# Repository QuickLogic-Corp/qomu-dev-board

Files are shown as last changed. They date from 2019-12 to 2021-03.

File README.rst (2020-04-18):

======================
Qomu Development Board
======================

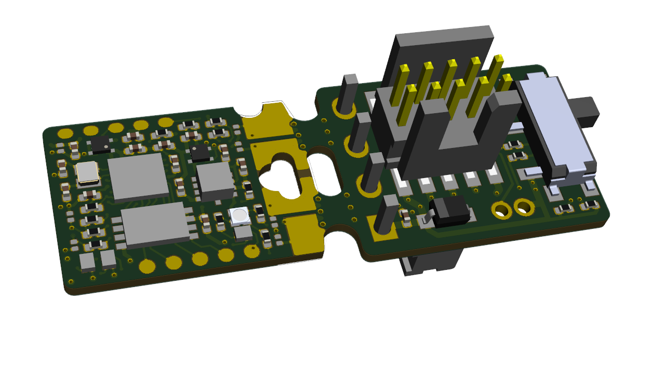
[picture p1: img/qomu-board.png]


Overview
========

This repository contains open hardware design files for a development board based on the Quicklogic `EOS S3 Sensor Processing Platform <https://www.quicklogic.com/products/eos-s3/>`_.
The design files were created by `Antmicro <https://www.antmicro.com>`_ in cooperation with `Quicklogic <https://www.quicklogic.com/>`_.
The board is small enough to fit into a USB socket.
This allows the user to explore functionalities of the EOS S3 platform on the go without cables or taking up space on your desk.
The board has an additional break-away part with debug connectors that speed up initial bringup and software development.

Key features
============

* EOS S3 Sensor Processing Platform
* 16Mbit of external flash memory
* Accelerometer
* User RGB LED
* Capacitive touch pads
* Supplied with 5.0VDC from USB port
* USB data signals tied to programmable logic

Layout and dimensions
=====================

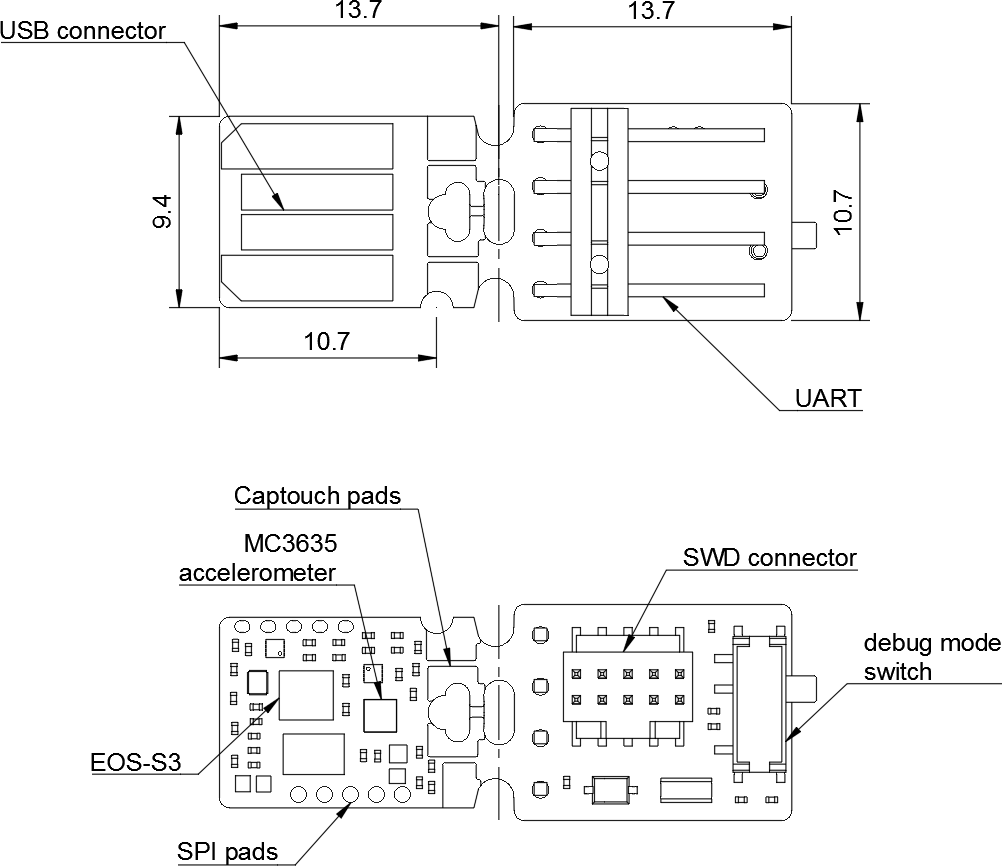
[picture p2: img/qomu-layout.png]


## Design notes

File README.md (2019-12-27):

# qomu-dev-board
Qomu Development Board for EOS S3

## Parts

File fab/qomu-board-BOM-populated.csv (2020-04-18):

Reference | Quantity | Value | Footprint | Manufacturer | MPN
C1 C2 C7 C9 | 4 | C_2u2_0201 | C_0201_0603Metric | Samsung | CL03A225MP3CRNC
C10 C11 C12 C3 C4 C5 C6 C8 | 8 | C_100n_0201 | C_0201_0603Metric | Murata | GRM033R60J104KE19D
C13 C14 | 2 | C_8p_0201 | C_0201_0603Metric | Murata | GRM0335C1E8R0DA01D
D1 D2 D3 D4 D5 D6 D7 | 7 | D_Small-Device | X1-DFN1006-2 | Diodes Inc. | D5V0L1B2LP3-7
D8 | 1 | SD05C.TCT | SOD-323-SD05 | Semtec | SD05C.TCT
IC1 | 1 | EOS-S3 | 42-WLCSP | Quicklogic | EOS-S3-42-WLCSP
J1 | 1 | FTSH-105-01-L-DV-K | PinHeader_2x5_P1.27_SMD | Samtec Inc. | FTSH-105-01-L-DV-K
J2 | 1 | 825437-4 | TE_825437-4 | TE Connectivity | 825437-4
J3 | 1 | MC-HVT1-S02-G | PinHeader_1x2_P1.27mm_Drill.7mm_with_622002115121_plug | Multicomp | MC-HVT1-S02-G
Q1 Q2 Q3 | 3 | RV1C002UN | VML0806 | ROHM Semiconductor | RV1C002UN
R1 R13 R15 R2 R3 R4 R5 R6 | 8 | R_10k_0201 | R_0201_0603Metric | Panasonic | ERJ1GNF1002C
R10 R7 | 2 | R_0R_0201 | R_0201_0603Metric | Multicomp | MCRE000086
R11 R12 | 2 | R_22R_0201 | R_0201_0603Metric | Multicomp | MCRE000100
R16 R17 | 2 | R_100R_0201 | R_0201_0603Metric | Multicomp | MCRE000116
R18 | 1 | R_220R_0201 | R_0201_0603Metric | Multicomp | MCRE000124
R8 | 1 | R_4k7_0201 | R_0201_0603Metric | Vishay | CRCW02014K70FNED
R9 | 1 | R_1k5_0201 | R_0201_0603Metric | Multicomp | MCRE000144
S1 | 1 | MSS3-V-T_R | Switch_Slide_MSS3 | Diptronics | MSS3-V-T/R
U1 U2 | 2 | LDO-X2SON | Texas_X2SON-4_1x1mm_P0.65mm | Microchip | MIC5504-3.3YMT
U10 | 1 | RGB-LED | LED-RGB-5DS-UHD1110-FKA | Cree | UHD1110-FKA
U4 | 1 | GD25Q16CEIGR | GD25Q16CEIGR | GigaDevice Semiconductor | GD25Q16CEIGR
U5 | 1 | MC3635 | MC3635 | mCube | MC3635
XTAL1 | 1 | ECS-_327-12_5-1210-TR | XTAL_ECS-.327-12.5-1210-TR | ECS Inc. | ECS-.327-12.5-1210-TR

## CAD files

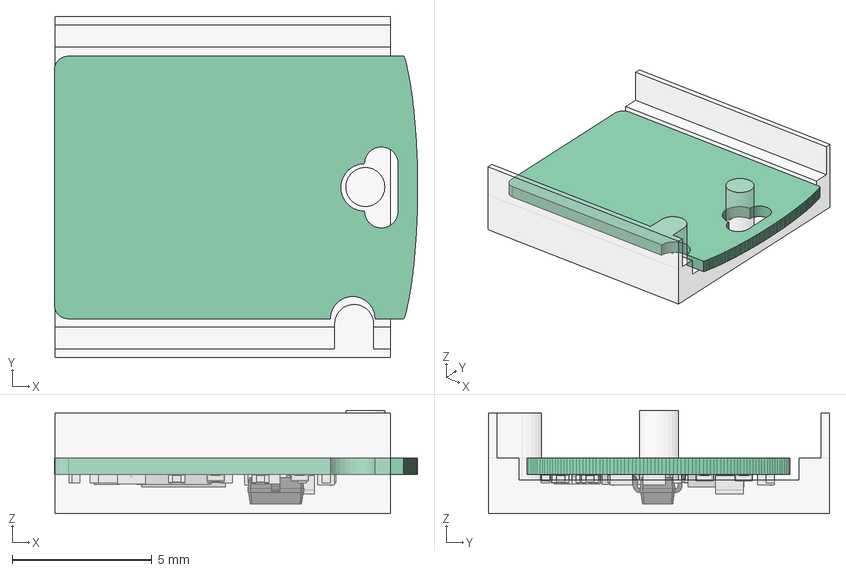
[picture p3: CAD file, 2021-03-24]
case/case-bare-0.0.FCStd
13.0 x 12.2 x 3.70 mm
Pcb
U2_X2SON-DQN0004A_5DC58CFF
U1_X2SON-DQN0004A_5F5B4CDF
U10_LED-UHD1110-FKA_5DC5D065
U4_(Unsaved)_5DEEC34D
Q3_TRANS_RV1C001Z_ROM_5DF3B6C3
Q1_TRANS_RV1C001Z_ROM_5F9A5F46
Q2_TRANS_RV1C001Z_ROM_5DF9400C
C4_C_0201_0603Metric_5FB65D3D
U3_SOT_323_SC_70_5FC7136C
C15_C_0201_0603Metric_5FB66156
XTAL1_ECS-.327-12.5-1210-TR_5DF79E47
IC1_(Unsaved)_5F5BD09C
C7_C_0201_0603Metric_5DDDC17D
R1_R_0201_5DC5A0F0
C14_C_0201_0603Metric_5F9A3241
C13_C_0201_0603Metric_5DF97F66
R18_R_0201_5DEE54FD
R17_R_0201_5DF3BC3D
R16_R_0201_5DF3BCFD
R12_R_0201_5DF3BC6D
R11_R_0201_5DF3BC9D
R9_R_0201_5DF3BCCD
R5_R_0201_5F5B4C73
R2_R_0201_5DDDC491
D7_L_0201_0603Metric_5DC58C89
D6_L_0201_0603Metric_5DF818F3
D5_L_0201_0603Metric_5F5BD1CB
D4_L_0201_0603Metric_5DEE9B1D
D3_L_0201_0603Metric_5DC59080
D2_L_0201_0603Metric_5DC59071
D1_L_0201_0603Metric_5F5BBC78
C11_C_0201_0603Metric_5F5B4CA3
C10_C_0201_0603Metric_5DEFCC06
C9_C_0201_0603Metric_5DD5522E
C8_C_0201_0603Metric_5DEFCCB7
C6_C_0201_0603Metric_5DEFCBD0
C5_C_0201_0603Metric_5DF7B985
C3_C_0201_0603Metric_5DEFCE4F
C2_C_0201_0603Metric_5F5B4C43
C1_C_0201_0603Metric_5DDDBFF4
Case

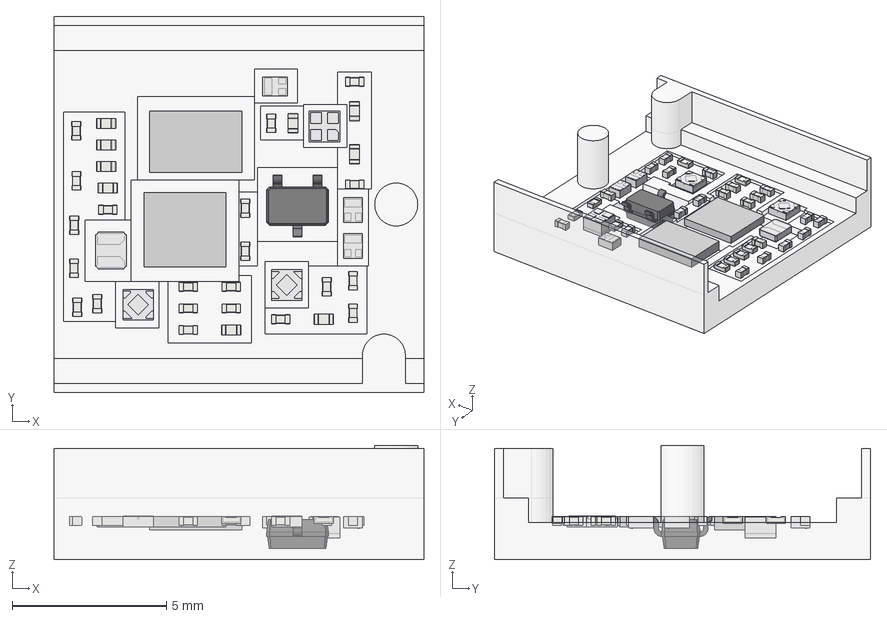
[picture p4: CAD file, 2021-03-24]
case/case-0.1.FCStd
12.0 x 12.2 x 3.70 mm
U2_X2SON-DQN0004A_5DC58CFF
U1_X2SON-DQN0004A_5F5B4CDF
U10_LED-UHD1110-FKA_5DC5D065
U4_(Unsaved)_5DEEC34D
Q3_TRANS_RV1C001Z_ROM_5DF3B6C3
Q1_TRANS_RV1C001Z_ROM_5F9A5F46
Q2_TRANS_RV1C001Z_ROM_5DF9400C
C4_C_0201_0603Metric_5FB65D3D
U3_SOT_323_SC_70_5FC7136C
C15_C_0201_0603Metric_5FB66156
XTAL1_ECS-.327-12.5-1210-TR_5DF79E47
IC1_(Unsaved)_5F5BD09C
C7_C_0201_0603Metric_5DDDC17D
R1_R_0201_5DC5A0F0
C14_C_0201_0603Metric_5F9A3241
C13_C_0201_0603Metric_5DF97F66
R18_R_0201_5DEE54FD
R17_R_0201_5DF3BC3D
R16_R_0201_5DF3BCFD
R12_R_0201_5DF3BC6D
R11_R_0201_5DF3BC9D
R9_R_0201_5DF3BCCD
R5_R_0201_5F5B4C73
R2_R_0201_5DDDC491
D7_L_0201_0603Metric_5DC58C89
D6_L_0201_0603Metric_5DF818F3
D5_L_0201_0603Metric_5F5BD1CB
D4_L_0201_0603Metric_5DEE9B1D
D3_L_0201_0603Metric_5DC59080
D2_L_0201_0603Metric_5DC59071
D1_L_0201_0603Metric_5F5BBC78
C11_C_0201_0603Metric_5F5B4CA3
C10_C_0201_0603Metric_5DEFCC06
C9_C_0201_0603Metric_5DD5522E
C8_C_0201_0603Metric_5DEFCCB7
C6_C_0201_0603Metric_5DEFCBD0
C5_C_0201_0603Metric_5DF7B985
C3_C_0201_0603Metric_5DEFCE4F
C2_C_0201_0603Metric_5F5B4C43
C1_C_0201_0603Metric_5DDDBFF4
Case

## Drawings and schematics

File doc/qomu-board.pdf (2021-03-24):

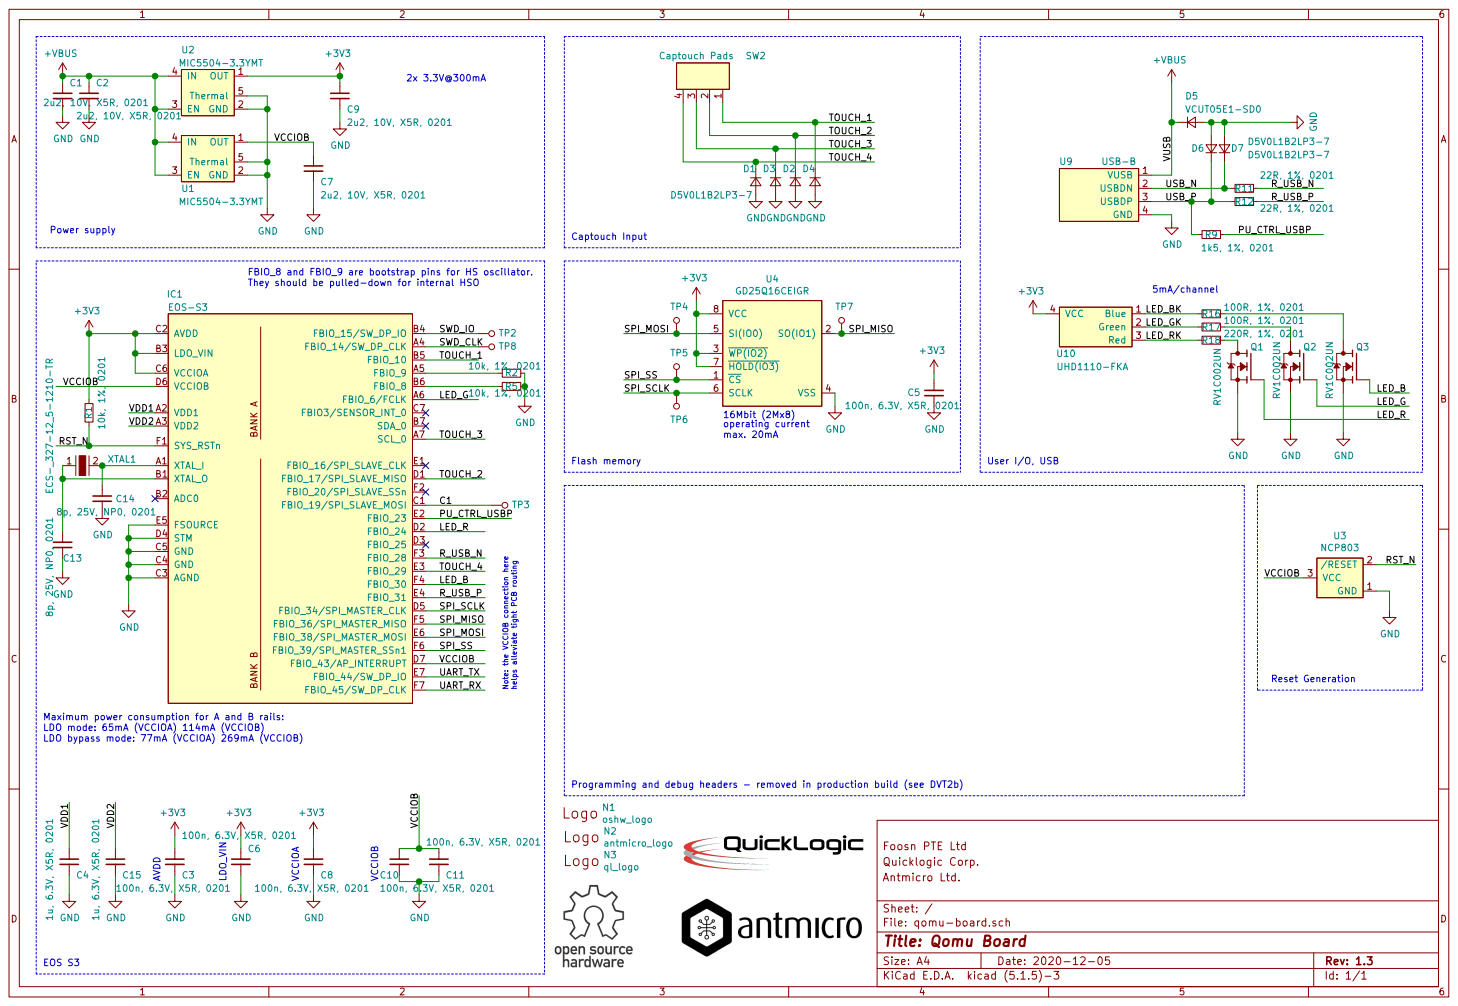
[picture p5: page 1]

They should be pulled-down for internal HSO VCCIOB

5mA/channel Note: the VCCIOB connection here helps alleviate tight PCB routing 2x 3.3V@300mA

FBIO_8 and FBIO_9 are bootstrap pins for HS oscillator.

SPI_MOSI Maximum power consumption for A and B rails:

File: qomu-board.sch Sheet: / Antmicro Ltd. Quicklogic Corp. Foosn PTE Ltd GND

LDO mode: 65mA (VCCIOA) 114mA (VCCIOB)
LDO bypass mode: 77mA (VCCIOA) 269mA (VCCIOB) LDO_VIN

Id: 1/1 Title: Qomu Board

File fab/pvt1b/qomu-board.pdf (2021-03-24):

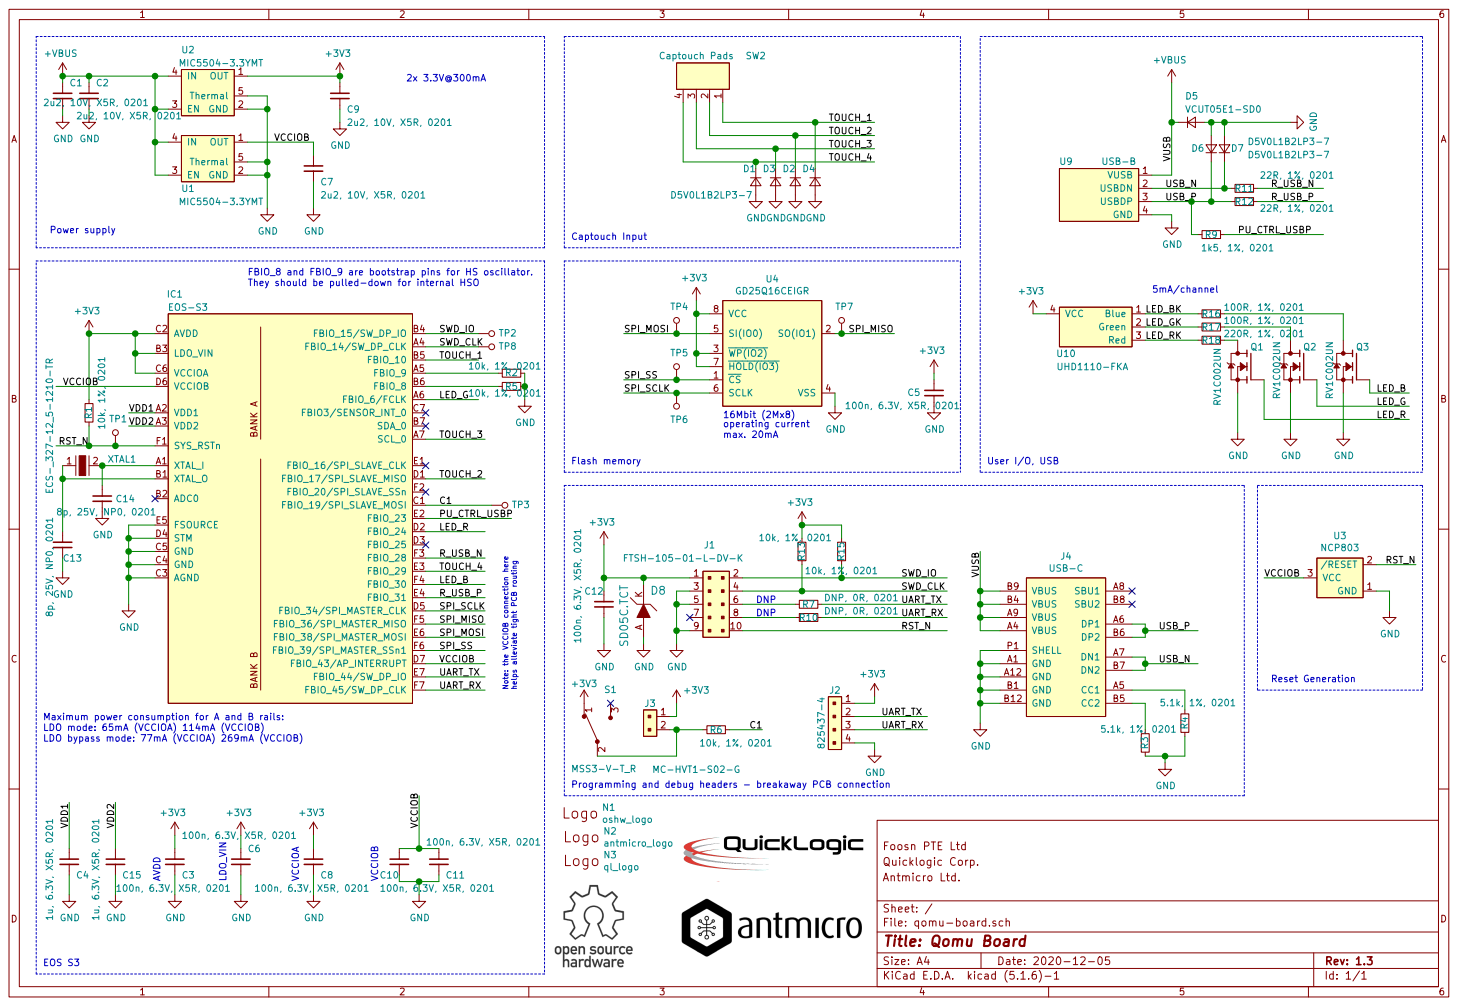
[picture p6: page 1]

1 Captouch Pads SW2 TP2 TP8 C4 1u, 6.3V, X5R, 0201 GND GND

They should be pulled-down for internal HSO LDO_VIN
IC1EOS-S3 GND GND

FBIO_8 and FBIO_9 are bootstrap pins for HS oscillator.

operating current max. 20mA AVDD

Programming and debug headers - breakaway PCB connection Note: the VCCIOB connection here helps alleviate tight PCB routing VCCIOB

SWD_CLK Maximum power consumption for A and B rails:

LDO mode: 65mA (VCCIOA) 114mA (VCCIOB)
LDO bypass mode: 77mA (VCCIOA) 269mA (VCCIOB)

File: qomu-board.sch Sheet: / Antmicro Ltd. Quicklogic Corp. Foosn PTE Ltd Logo N2

Id: 1/1 Title: Qomu Board

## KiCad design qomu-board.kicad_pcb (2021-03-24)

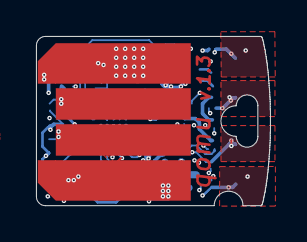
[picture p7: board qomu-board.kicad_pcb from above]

Board: 4 copper layers, 13.0 x 9.4 mm, 52 parts (0 on the bottom side), 36 nets.

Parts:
C1, C2, C7, C9: 2u2, 10V, X5R, 0201; C_0201_0603Metric
C3, C5, C6, C8, C10, C11: 100n, 6.3V, X5R, 0201; C_0201_0603Metric
C4: 1u, 6.3V, X5R, 0201; C_0201
C13, C14: 8p, 25V, NP0, 0201; C_0201_0603Metric
C15: 1u, 6.3V, X5R, 0201; C_0201_0603Metric
D1, D2, D3, D4, D6, D7: D5V0L1B2LP3-7; X1-DFN1006-2
D5: VCUT05E1-SD0; X1-DFN1006-2
IC1: EOS-S3; 42-WLCSP
N1: oshw_logo; OSHW-Logo2_7.3x6mm_Copper_Mask
N2: antmicro_logo; antmicro-logo_midlayer_4mm
N3: ql_logo; Ql_logo_mid_9mm
Q1, Q2, Q3: RV1C002UN; VML0806
R1, R2, R5: 10k, 1%, 0201; R_0201_0603Metric
R9: 1k5, 1%, 0201; R_0201_0603Metric
R11, R12: 22R, 1%, 0201; R_0201_0603Metric
R16, R17: 100R, 1%, 0201; R_0201_0603Metric
R18: 220R, 1%, 0201; R_0201_0603Metric
SW2: Captouch Pads; captouch-edge
TP2, TP3, TP8: TP_SMD_0_75MM; Testpoint_smd_0_75_0_6mm
TP4, TP5, TP6, TP7: TP_SMD_0_75MM; Testpoint_pad_1mm
U1, U2: MIC5504-3.3YMT; Texas_X2SON-4_1x1mm_P0.65mm
U3: NCP803; SC-70_SOT-323
U4: GD25Q16CEIGR
U9: USB-B; USB-PCB
U10: UHD1110-FKA; LED-RGB-5DS-UHD1110-FKA
XTAL1: ECS-_327-12_5-1210-TR; XTAL_ECS-.327-12.5-1210-TR

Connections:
+3V3: C3.1, C5.2, C6.1, C8.1, C9.1, IC1.B3, IC1.C2, IC1.C6, R1.2, U2.1, U4.3, U4.7, U4.8, U10.4
+VBUS: C1.1, C2.1, D5.1, U1.3, U1.4, U2.3, U2.4, U9.1
/C1: IC1.C1, TP3.1
/LED_B: IC1.F4, Q3.1
/LED_BK: R16.2, U10.1
/LED_G: IC1.A6, Q2.1
/LED_GK: R17.2, U10.2
/LED_R: IC1.D2, Q1.1
/LED_RK: R18.2, U10.3
/PU_CTRL_USBP: IC1.E2, R9.1
/RST_N: IC1.F1, R1.1, U3.2
/R_USB_N: IC1.F3, R11.1
/R_USB_P: IC1.E4, R12.1
/SPI_MISO: IC1.F5, TP7.1, U4.2
/SPI_MOSI: IC1.E6, TP4.1, U4.5
/SPI_SCLK: IC1.D5, TP6.1, U4.6
/SPI_SS: IC1.F6, TP5.1, U4.1
/SWD_CLK: IC1.A4, TP8.1
/SWD_IO: IC1.B4, TP2.1
/TOUCH_1: D4.1, IC1.B5, SW2.1
/TOUCH_2: D2.1, IC1.D1, SW2.2
/TOUCH_3: D3.1, IC1.A7, SW2.3
/TOUCH_4: D1.1, IC1.E3, SW2.4
/USB_N: D7.1, R11.2, U9.2
/USB_P: D6.1, R9.2, R12.2, U9.3
/VCCIOB: C7.1, C10.1, C11.1, IC1.D6, IC1.D7, U1.1, U3.3
/VDD1: C4.1, IC1.A2
/VDD2: C15.1, IC1.A3
GND: C1.2, C2.2, C3.2, C4.2, C5.1, C6.2, C7.2, C8.2, C9.2, C10.2, C11.2, C13.2, C14.2, C15.2, D1.2, D2.2, D3.2, D4.2, D5.2, D6.2, D7.2, IC1.C3, IC1.C4, IC1.C5, IC1.D4, IC1.E5, Q1.2, Q2.2, Q3.2, R2.2, R5.1, U1.2, U1.5, U2.2, U2.5, U3.1, U4.4, U9.4
unnamed: C13.1, IC1.B1, XTAL1.1
unnamed: C14.1, IC1.A1, XTAL1.2
unnamed: IC1.A5, R2.1
unnamed: IC1.B6, R5.2
unnamed: Q1.3, R18.1
unnamed: Q2.3, R17.1
unnamed: Q3.3, R16.1

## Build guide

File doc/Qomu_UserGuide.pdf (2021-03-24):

# Qomu Low Power MCU Open Source Hardware Development Kit

## User Guide (Rev 1.0)

This document serves as a guide for the user to getting started with the Qomu board.

This guide provides users with functional descriptions, configuration options for the Qomu Low Power MCU Open

Source Hardware Development Kit. It also serves as a “Getting Started” and “How To” guide.

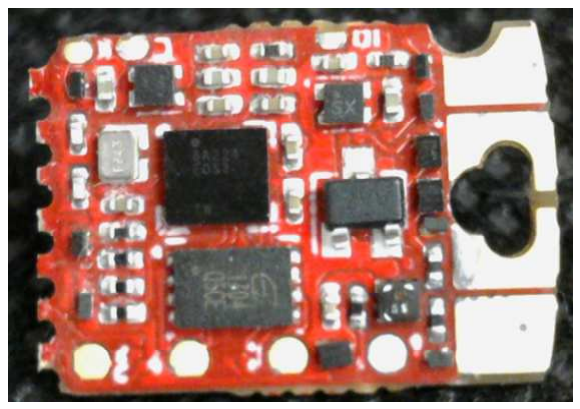
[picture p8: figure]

Figure 1: Qomu Low Power MCU Open Source Hardware Development Kit

## Qomu Low Power MCU Open Source Hardware Development Kit Overview

The Qomu Low Power MCU Open Source Hardware Development Kit (HDK) is a small form factor system ideal for exploring MCU + eFPGA development. Unlike other development kits which are based on proprietary hardware and software tools, Qomu is based on 100% open source hardware and is built around 100% open source software (including the Symbiflow FPGA Tools).

The Qomu HDK is powered by QuickLogic’s EOS™ S3 (https://www.quicklogic.com/products/eos-s3/), the first eFPGAenabled Arm CortexⓇ-M4F MCU to be fully supported with Zephyr RTOS and FreeRTOS. Other functionality includes:

- QuickLogic EOS S3 MCU Platform
- 16Mbit of on-board flash memory
- Touchpads (4) and RGB LED
- Powered from USB
- USB data signals tied to programmable logic

Benefits

- Qomu HDK is small, fitted in a PC USB slot, inexpensive, and is 100% supported by open source tools.

- With a Cortex M4F MCU and integrated eFPGA, the EOS S3 lets you innovate with 100% open source hardware and software.

Applications

- Tiny ML applications (such as with SensiML’s AI Software Platform and Google’s TensorFlow Lite) with eFPGA as accelerator engine
- General purpose MCU applications

## Getting Started

What You Need

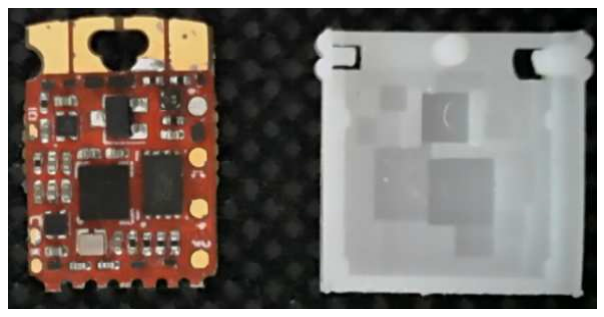
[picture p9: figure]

Figure 2: Qomu & Plastic housing

- 1 × Qomu HDK development board
- 1x Qomu USB plastic housing
- 1 x Micro-USB 2.0 extension cable¹ , Type A (male) to Type A (female) for Power and easy of connecting to PC
- Laptop (Win10 OS²
or Linux OS) running terminal program (such as PuTTY³ or any UART console
application)

Note¹, 2,3:

1
you will need to provide your own USB cable

2
Windows 7 and Windows 8 are not supported

3
PuTTY download & installation: https://www.putty.org/

Running pre-loaded program from Flash

The purpose of the pre-loaded program is to make it very fast and straightforward for a new user to verify the board is functioning correctly. While we do production testing of every Qomu HDK before we ship, sometimes things happen during shipping or storage. Running this test takes less than a minute to do, requires no knowledge of the HDK, and will give you peace of mind the HDK is ready for you to start innovating freely.

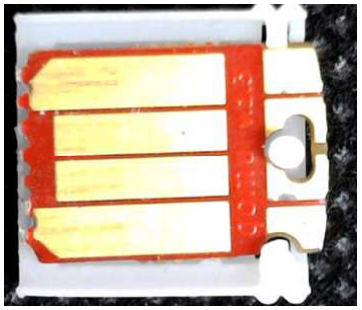
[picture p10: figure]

Figure 3: Qomu insert into Plastic housing

1. Place the Qomu board into the plastic housing.
2. Insert the housing into USB extension cable or PC USB port; recommend using USB extension cable for easy to connect and disconnect to PC. We also recommend USB hub with on/off button.
3. Upon power applied to the board, the LED flashes blue color for 5 seconds and then turns off.
4. Wait for 5 seconds.
5. On Windows 10 machine, open Device Manager to check for the assign COM port.

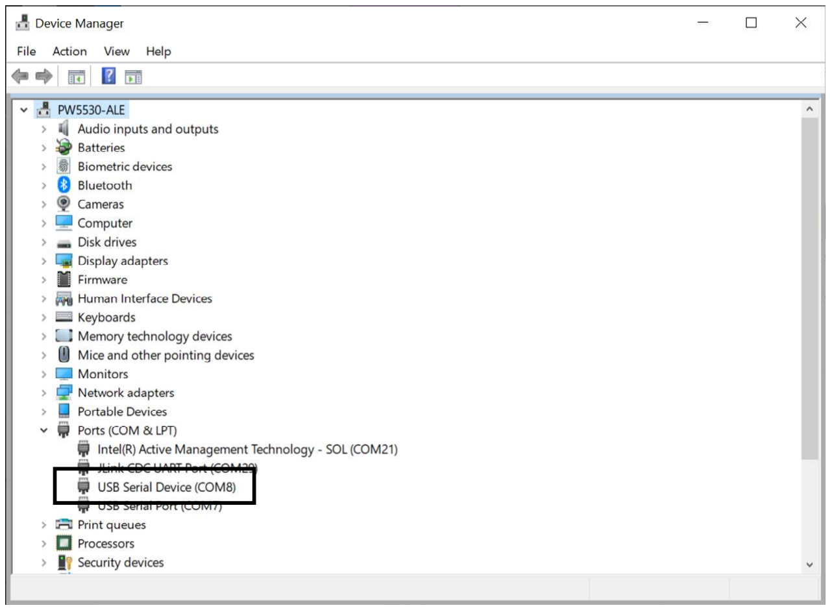
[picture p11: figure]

Figure 4: Checking COM Port with Device Manager

Note: for Win10 system, the system device manager may not fully configure Qomu as COM port when install for the first time, disconnect the power from the module and repeat step (3) to (6).

6. Launch PuTTY application and configure for Serial access and select “Open”.

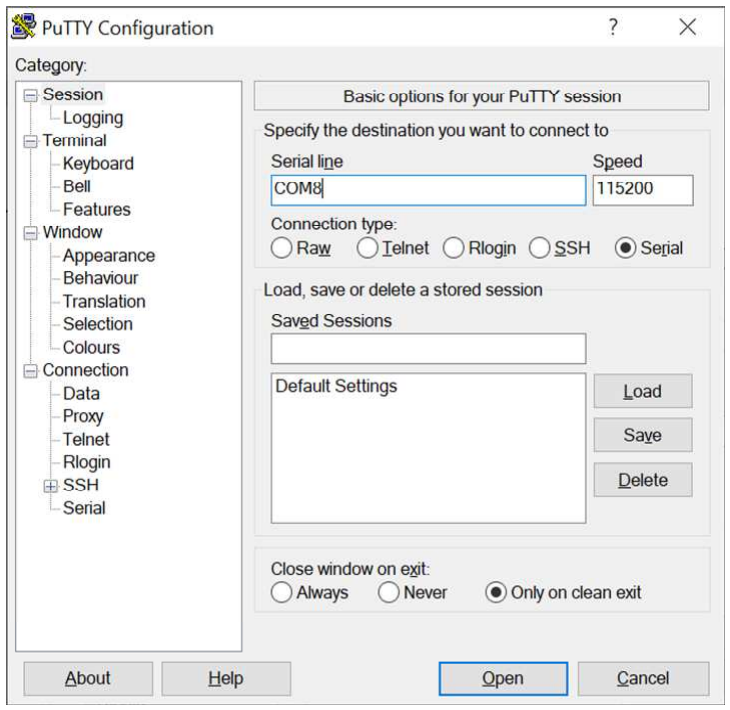
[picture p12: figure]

Figure 5: Putty setup for COM port access

### 7. Perform the followings in the PuTTY terminal:

a) Type: “diag” to bring up Qomu diagnostic menu
b) Type: “help” to bring up the menu of commands
c) Type: “red”; the command shows red color for LED
d) Type: “red”; the LED turns off the LED
e) Try “green” and “blue”

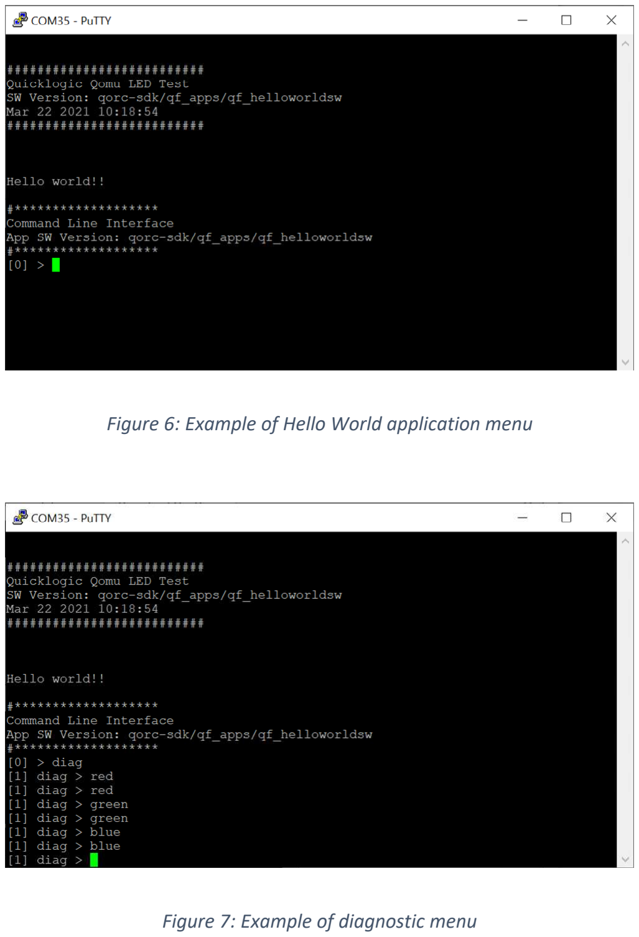
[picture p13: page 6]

Figure 6: Example of Hello World application menu

Figure 7: Example of diagnostic menu

## Board Layout Overview

Components on the Board

- QuickLogic EOS S3 MCU Platform
- 16Mbit of on-board flash memory
- RGB LED
- 4 User Touch Pads
- IO signals break-routed into test points

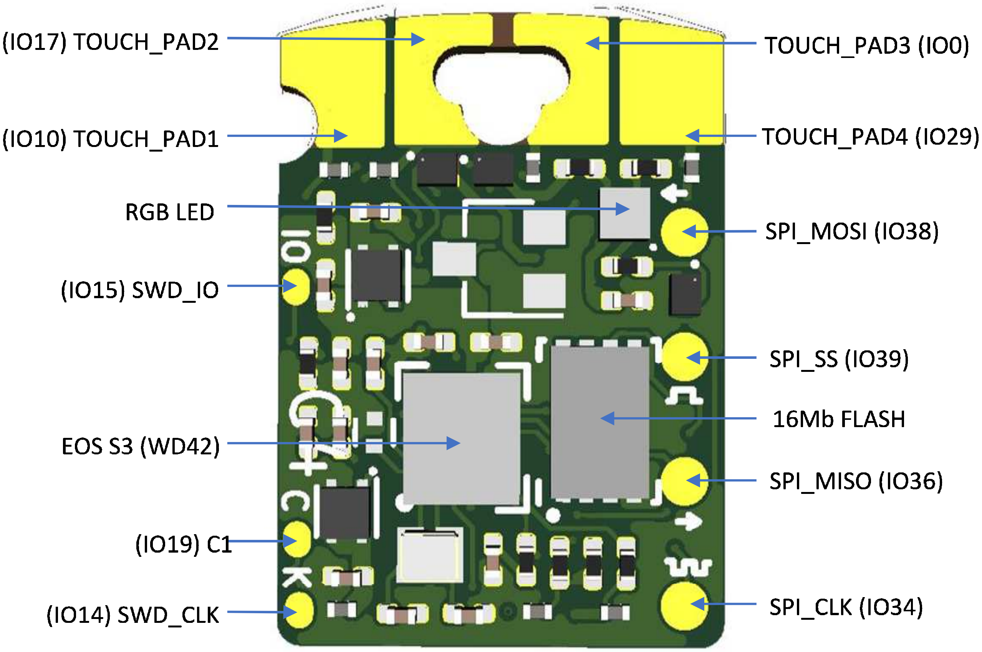
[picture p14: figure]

Figure 8: Qomu HDK Board Overview

## Qomu HDK power supplies

Qomu HDK power is supplied via USB pads

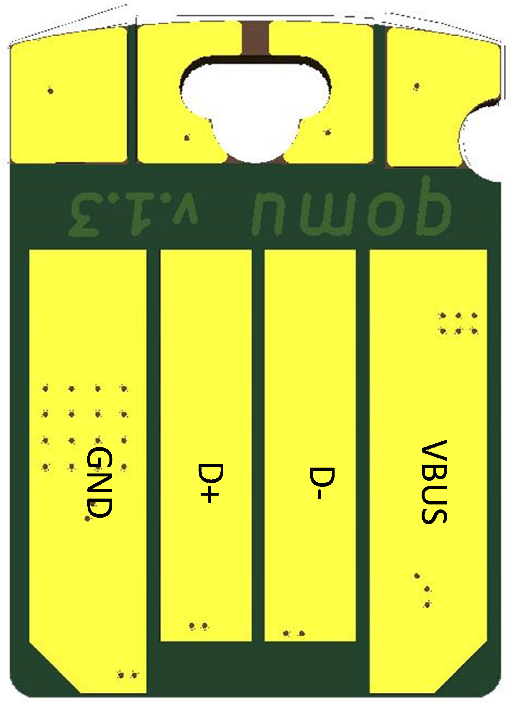
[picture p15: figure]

Figure 9: Qomu HDK Power input

## Flashing Binaries to Qomu HDK

Qomu supports loading and testing stand-alone eFPGA design or eFPGA + M4 MCU design, using the pre-programmed bootloader and flash-loading binaries. Recommend to only update standalone M4 application, M4+FPGA application or standalone FPGA application.

In each case, the procedure is the same.

IMPORTANT: do not overwrite bootloader area and the bootfpga area. Overwrite these areas may make the Qomu HDK fail to boot properly and can’t be recovered without specialize hardware.

Procedure
1. Remove USB power from the Qomu HDK.
2. Apply USB Power.
3. While the blue LED is blinking (for 5 seconds), touch the touch-pads with finger; if success, the green led will start flashing.
4. Check the COM port assigned COM value; see figure 3 for example of finding COM port in Windows 10 OS.
5. Use TinyFpgaProgrammer application to load the target application. Refer to https://github.com/QuickLogic-Corp/TinyFPGA-Programmer-Application for detail information on installation and program usage.

Example (for Windows 10 OS)
- Flashing Qomu with standalone FPGA example, execute and reflash Qomu with the original HelloworldSW

application. All required binaries are available under QORC-SDK: https://github.com/QuickLogic-Corp/qorc-sdk/tree/master/qomu_apps/qomu-initial-binaries.
- Checkout TinyFPGA-Programmer-Application to local driver and follow instructions from the readme.rst.

Flashing Qomu with standalone FPGA application

- Open CMD console.
- Change directory to location of TinyFPGA-Programmer-Application.
- Execute Procedure step (1) to (4).
- For step 5, type: “ python.exe tinyfpga-programmer-gui.py --mode fpga --port [PC COMPORT] -appfpga [location

of binaries]\qomu_breath.bin --reset “.
Note: tiny application writes the fpga breath application to flash; the application issues the system reset upon completion; the system blinks blue led for 5 seconds and load the breath application; after few seconds, the RGB led will shows breathing of various color. For more information with regard to the application operation, see https://github.com/coolbreeze413/qorc-onion-apps/tree/master/qorc_fpga_breathe.

Flashing Qomu with HelloworldSW application

- Open CMD console.
- Change directory to location of TinyFPGA-Programmer-Application.
- Execute Procedure step (1) to (4).
- For step 5, type: “ python.exe tinyfpga-programmer-gui.py --mode m4 --port [PC COMPORT] -m4app [location of

binaries]\qomu_helloworldsw.bin --reset “.

Note: see Running Pre-load Application section for details.

## Revision

Version | Date | Revision
1.0 | March 2021 | First release

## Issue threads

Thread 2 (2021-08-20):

Can't get board to function as expected.

brendanrankin, 2021-08-20:
Just received the QOMU board from CrowdSupply via Mouser. When I plug the it into the USB slot out of the box, I wait until the blue lights stop flashing, etc...and then I try to connect to /dev/ttyACM0 (the serial port that it shows up on) and...the board appears to crash with it eventually losing connection to USB with messages like these:
===
[Fri Aug 20 00:06:22 2021] usb 1-7: reset full-speed USB device number 53 using xhci_hcd
[Fri Aug 20 00:06:22 2021] usb 1-7: device descriptor read/64, error -71
[Fri Aug 20 00:06:22 2021] usb 1-7: device descriptor read/64, error -71
[Fri Aug 20 00:06:22 2021] usb 1-7: reset full-speed USB device number 53 using xhci_hcd
[Fri Aug 20 00:06:22 2021] usb 1-7: device descriptor read/64, error -71
[Fri Aug 20 00:06:22 2021] usb 1-7: device descriptor read/64, error -71
[Fri Aug 20 00:06:23 2021] usb 1-7: reset full-speed USB device number 53 using xhci_hcd
[Fri Aug 20 00:06:23 2021] usb 1-7: Device not responding to setup address.
[Fri Aug 20 00:06:23 2021] usb 1-7: Device not responding to setup address.
[Fri Aug 20 00:06:23 2021] usb 1-7: device not accepting address 53, error -71
[Fri Aug 20 00:06:23 2021] usb 1-7: reset full-speed USB device number 53 using xhci_hcd
[Fri Aug 20 00:06:23 2021] usb 1-7: Device not responding to setup address.
[Fri Aug 20 00:06:23 2021] usb 1-7: Device not responding to setup address.
[Fri Aug 20 00:06:24 2021] usb 1-7: device not accepting address 53, error -71
[Fri Aug 20 00:06:24 2021] usb 1-7: USB disconnect, device number 53
[Fri Aug 20 00:06:24 2021] usb 1-7: new full-speed USB device number 54 using xhci_hcd
[Fri Aug 20 00:06:24 2021] usb 1-7: device descriptor read/64, error -71
[Fri Aug 20 00:06:24 2021] usb 1-7: device descriptor read/64, error -71
[Fri Aug 20 00:06:24 2021] usb 1-7: new full-speed USB device number 55 using xhci_hcd
[Fri Aug 20 00:06:24 2021] usb 1-7: device descriptor read/64, error -71
[Fri Aug 20 00:06:25 2021] usb 1-7: device descriptor read/64, error -71
[Fri Aug 20 00:06:25 2021] usb usb1-port7: attempt power cycle
[Fri Aug 20 00:06:25 2021] usb 1-7: new full-speed USB device number 56 using xhci_hcd
[Fri Aug 20 00:06:25 2021] usb 1-7: Device not responding to setup address.
[Fri Aug 20 00:06:25 2021] usb 1-7: Device not responding to setup address.
[Fri Aug 20 00:06:25 2021] usb 1-7: device not accepting address 56, error -71
[Fri Aug 20 00:06:26 2021] usb 1-7: new full-speed USB device number 57 using xhci_hcd
[Fri Aug 20 00:06:26 2021] usb 1-7: Device not responding to setup address.
[Fri Aug 20 00:06:26 2021] usb 1-7: Device not responding to setup address.
[Fri Aug 20 00:06:26 2021] usb 1-7: device not accepting address 57, error -71
[Fri Aug 20 00:06:26 2021] usb usb1-port7: unable to enumerate USB device
===
I tried to get it into a mode where I could program something else using the Python programmer, but I can't get the touchpad "fingers" to function at all.

Time to ship it back? If so, where/how do I ship it and will you cover the cost? ;-)

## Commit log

2019-12-27 Initial files for qomu board
    [qomu-board-B_Adhes.gbr, qomu-board-B_CrtYd.gbr, qomu-board-B_Fab.gbr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]
2019-12-27 Initial upload of lib folder for Qomu board
2020-04-17 Add PDF of the qomu board schematic
2020-04-17 Update Kicad design file
    [qomu-board.kicad_pcb]
2020-04-18 Update Qomu design with latest design files and generated gerber
    [qomu-board-BOM-populated.csv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]
2020-08-07 Schematic Update: 1. Remove accel sensor and related passive components 2. Add QL to title Layout Update: 1. Remove accel sensor and related passive components 2. Remove stranded nets: I2C SCL, I2C S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
    Remains: check stranded via for 3.3V and GND
    [qomu-board.kicad_pcb, qomu-board.sch]
2021-03-24 Update to latest HW revision
    [case-0.1.FCStd, case-bare-0.0.FCStd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]

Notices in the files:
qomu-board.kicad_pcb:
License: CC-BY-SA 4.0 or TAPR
